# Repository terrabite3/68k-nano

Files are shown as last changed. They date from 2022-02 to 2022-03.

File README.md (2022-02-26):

# 68k nano

A minimal single-board computer based on the venerable ["Texas Cockroach"](https://youtu.be/UaHtGf4aRLs?t=2074)
Motorola 68000 16/32-bit microprocessor.

Board image

## Features

- 68HC000 processor running at 12MHz
- 1MB RAM
- 64KB ROM
- 16550 UART providing a 5V FTDI serial port
- 44-pin IDE connector for CompactFlash card adapter
- Connector for SparkFun DS3234 real-time clock
- Only two 74HC glue logic chips required

This might be capable of running uClinux, but I haven't tried it!

## Hardware

The 68k nano hardware is simple and straightforward. It can be built on a
breadboard (though there may be stability issues at higher clock speeds).

### Memory map

Due to the minimal address decoding circuitry, accessing certain memory regions
will cause multiple devices to be selected. This should be avoided.

```
$000000-0xFFFF     ROM (repeats 16 times)
$100000-1FFFFF  X  Forbidden (multiple devices selected)
$200000-2FFFFF     ROM (mirror of $000000-0FFFFF)
$300000-7FFFFF  X  Forbidden (multiple devices selected)
$800000-8FFFFF     Open bus (available for expansion)
$900000-9xxxxF     CompactFlash card
$A00000-AxxxxF     UART
$B00000-BFFFFF  X  Forbidden (multiple devices selected)
$C00000-CFFFFF     RAM
$D00000-DFFFFF  X  Forbidden (multiple devices selected)
$E00000-EFFFFF     RAM (mirror of $C00000-CFFFFF)
$F00000-FFFFFF  X  Forbidden (multiple devices selected)
```

This is summarized with the following equations:

```
/ROMSEL  = /A23
/RAMSEL  =  A22
/UARTSEL =  A23 * /A22 * A21
/CARDSEL =  A20
```

### I/O

The 16550's modem control lines are used as a bit-banged SPI interface. A 7-pin
header is provided for [SparkFun's "DeadOn" DS3234 real-time clock board](https://www.sparkfun.com/products/10160).
Access to SPI is therefore achieved via the 16550's Modem Control Register and Line
Status Register.

A 2mm pitch 44-pin IDE connector is provided for storage devices. This is
intended for CompactFlash card adapters (operating in 16-bit True IDE mode) but
may also work with parallel ATA hard disks. (not tested)

### Interrupts

All interrupt sources are routed through the 16550. All 16550 interrupts invoke
the level 1 autovector (vector offset `$064`) and it is up to the software to
determine the source of the interrupt.

### Building it

`bom.txt` contains a bill of materials. As of this writing (July 2020), all
components are available from major distributors like [Mouser](https://mouser.com)
and [Jameco](https://jameco.com). If purchasing 68000s from eBay, note that [vintage
ICs are a common target of counterfeiters](https://medium.com/supplyframe-hardware/the-underground-parts-store-identifying-counterfeit-computer-chips-3020adbb01f7).
For this project I used [Toshiba TMP68HC000P-12 chips from Jameco](https://www.jameco.com/shop/ProductDisplay?catalogId=10001&langId=-1&storeId=10001&productId=2288039) and
they work just fine.

All parts are through-hole for that extra vintage feel. Note that some of the
decoupling capacitors (C4, C5, C6, C8, and C10) are underneath ICs, so open-frame
IC sockets are required. Large IC sockets can also be expensive (_especially_
DIP-64 sockets!) so a cheaper alternative is to use [breakaway SIP 0.1" machine-pin
headers](https://www.amazon.com/dp/B0187LTEX2/ref=cm_sw_em_r_mt_dp_U_M5IbFbVJ3NVDH).

Due to the spacing of the chips, Textool ZIF sockets won't fit. For the ROMs
U5 and U7, [Aries 28-526-10 low-profile ZIF sockets](https://www.jameco.com/shop/ProductDisplay?catalogId=10001&langId=-1&storeId=10001&productId=102745) will fit,
but _barely_. The release latch may scrape against the RAM IC to its north,
but I've found that it's not a huge deal.

You can use either a full-can or half-can oscillator for X1. Note that if using
an oscillator with a frequency other than 12 MHz, you'll have to update the `F_CPU`
value in the Makefile. (see below) Also note that, if using a 68HC000, the minimum
clock frequency is 4 MHz.

The 44-pin IDE header accepts a CompactFlash adapter board such as [this one](https://www.amazon.com/gp/product/B07Y2MTS13), available from Amazon and other vendors.

## Software

This project uses the [vasm](http://sun.hasenbraten.de/vasm/) assembler and a
standard Makefile. Python 3 and [PySerial](https://pythonhosted.org/pyserial/)
are also required to upload programs to the computer via the serial port. The
Makefile also contains rules for burning ROM images to AT28C256 EEPROMs using
[minipro](https://gitlab.com/DavidGriffith/minipro/) if you have a [TL866II+](https://www.jameco.com/shop/ProductDisplay?catalogId=10001&langId=-1&storeId=10001&productId=2297823)
programmer. (If you don't have a chip programmer, you should get a TL866II+, they
are reasonably priced and available from a number of vendors.)

### Building it

Running `make rom` will build the ROM image and split it into "odd" and "even"
halves, `rom-l.bin` and `rom-u.bin`. Each file should be 32,768 bytes exactly.
Running `make burnrom` will write these files to a pair of AT28C256 EEPROMs
using minipro.

**Note:** if using an oscillator with a frequency other than 12 MHz, change the
value of `F_CPU` appropriately in the Makefile.

The `BAUD` variable in the Makefile sets the baud rate of the serial interface.
Use the included script `baudrate.py` to determine which baud rates are usable
with a given oscillator frequency.

### ROM features

The ROM is fairly minimal--it's closer to a bootloader than an operating system.
It supports loading programs from the root directory of a FAT16-formatted
CompactFlash card and some basic debugging functionality. It also provides a
small set of system calls for I/O to simplify application programs.

The power-up process is as follows:
- Initialize serial port to 57600 baud, 8 data bits, no parity, 1 stop bit.
- Test RAM. If a RAM failure occurs, the failed address is written to the serial
port and the Status LED flashes rapidly. (This is prone to failure when running
on a breadboard at higher clock speeds.)
- Check for the real-time clock module. If found, print the current date and
time to the serial port.
- Check for a CompactFlash card, and attempt to mount the first partition if it
is FAT16-formatted.
- If the "ENTER" pushbutton is NOT held down:
  - If a valid card is inserted, check for a file in the root directory named
    `STARTUP.BIN`. If found, load it into RAM and execute it.
  - If `STARTUP.BIN` was not loaded, enter an interactive command shell.
- If the "ENTER" pushbutton is held down, enter the interactive command shell
  and bypass execution of `STARTUP.BIN`.

Example startup sequence (without `STARTUP.BIN`):
```
68K NANO - ROM VERSION 00009900 (20200708)
(C) 2020 MATT SARNOFF (MSARNOFF.ORG)
TESTING RAM...PASSED

RAM: 1,048,576 BYTES
ROM: 65,536 BYTES
CPU: 12,000,000 HZ
TIME IS 2020-07-07 19:14:36
CARD DETECTED: 250,608 KB 'NO NAME    '
CANNOT LOAD STARTUP.BIN - FILE NOT FOUND

TYPE ? [ENTER] FOR HELP.
>
```

### Command shell

If `STARTUP.BIN` was not loaded, an interactive command shell is available via
the serial port. (57600 baud, 8 data bits, no parity, 1 stop bit). Type `?` and
press Enter for a list of supported commands. They are summarized briefly here.
Note that commands and filenames are _case-insensitive_.

- `.L` - list files in the root directory of the CompactFlash card. Long filenames
  and hidden files are not displayed.
- `.I` - print low-level information about the filesystem on the CompactFlash card.
- `.P file` - print the contents of the file named `file` in the root directory
  of the CompactFlash card as ASCII text.
- `.H file` - print the contenxt of the file named `file` in the root directory
  of the CompactFlash card as a hexdump.
- `.T` - print the current date and time as reported by the real-time clock module.
- `.T YYYYMMDDWWhhmmss` - set the current date and time. The new date/time should
  be expressed as a string of 16 decimal digits with no separators. `WW` should
  be a 2-digit weekday between `01` and `07` inclusive. You can obtain the
  current date/time in this format with the Unix command `date "+%Y%m%d0%u%H%M%S"`.
- `.D` - enter the debugger.
- `file` - any other command is interpreted as a filename to be loaded from the
  root directory of the CompactFlash card and executed. Unlike MS-DOS, the file
  extension _is_ required. e.g. to execute the file named _foo.bin_, enter `FOO.BIN`.
  (`FOO` will attempt to load a file named _foo_ with no extension).

### Serial loader

A break condition on the serial input line enters the serial loader, allowing
programs to be uploaded to RAM from a host computer. The Python script `serload.py`
and the Makefile rules `make load` and `make run` take care of this.

### Debugging

A hardware exception causes a transfer into a basic debugger. The Status LED
flashes rapidly and a register dump is printed to the serial port:

```
*ILLEGAL INSTRUCTION
D0=00000064  D1=0000000A  D2=00000038  D3=00000009
D4=00000000  D5=00000000  D6=00000000  D7=00000000
A0=00E0003C  A1=00001D40  A2=00000000  A3=00F00000
A4=00000000  A5=00000000  A6=000001E2  A7=00EFFFFA
SR=-S0--Z--  PC=00001D3A              USP=7F7EFFDF

[A]BORT/[C]ONTINUE/[S]TEP?
```

Supported commands are:
- `a` - abort execution and return to system.
- `c` - (attempt to) continue execution. (the Trace bit is cleared)
- `s` - set the Trace bit and single-step.

`TRAP #15` is treated as a breakpoint instruction that also enters the debugger.

### API

See `API.md` for a detailed description of the system calls provided by the ROM
API and guidelines for application programs.

## Known issues and shortcomings

- ROM is always present at the bottom of the address space, so the exception
  vectors cannot be overridden by application code.
- Interrupt handling is a hack, since all interrupt sources go through the 16550.
- Address decoding leaves little room for expansion.
- System calls should set the condition codes to simplify application code.

## Future directions

This is a small-scale project. I'm thinking about desiging a larger 68000 board
in the future, so I probably won't continue working on this one. Here are some
project ideas that I won't have time to tackle, but you're welcome to:

- Running an existing 68k monitor like [TUTOR](http://www.easy68k.com/paulrsm/mecb/mecb.htm)
  or [zBug](http://www.kswichit.com/68k/68k.html).
- Running a language like [EhBASIC](https://github.com/jefftranter/68000/tree/master/ehbasic) or a Forth.
- Adding FAT16 write support.
- Booting [uClinux](https://www.bigmessowires.com/2014/11/17/68-katy-68000-linux-on-a-solderless-breadboard/) like Steve Chamberlin did with [68 Katy](https://www.bigmessowires.com/category/68katy/).
- Using the DS3234 real-time clock's SQW output to generate a periodic interrupt.
  (likely necessary for uClinux)

## About

Open hardware, released under the terms of the 3-clause BSD license.

Copyright 2020 Matt Sarnoff.

http://twitter.com/txsector

http://msarnoff.org

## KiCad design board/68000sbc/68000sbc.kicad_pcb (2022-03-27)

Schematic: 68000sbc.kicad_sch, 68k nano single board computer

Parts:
C1, C2, C3, C4, C5, C6, C7, C8, C9, C10: 0.1uF; C_Rect_L7.0mm_W2.0mm_P5.00mm
C11, C12: 10uF; CP_Radial_D5.0mm_P2.50mm
D1, D2: 1N5817; D_DO-35_SOD27_P7.62mm_Horizontal
D3: POWER; LED_D5.0mm
D4: LED; LED_D5.0mm
D5: CARD; LED_D5.0mm
D6: HALT; LED_D5.0mm
J1: USB_B; USB_B_OST_USB-B1HSxx_Horizontal
J2: 5V FTDI SERIAL; PinHeader_1x06_P2.54mm_Horizontal
J3: RTC (SparkFun BOB-10160); PinHeader_1x07_P2.54mm_Vertical
J4: CFCARD/IDE; PinHeader_2x22_P2.00mm_Vertical
J5: EXPANSION (F.Cu); PadRow_1x25_P2.54mm
J6: EXPANSION (B.Cu); PadRow_1x25_P2.54mm
JP1: POWER SELECT; PinHeader_1x03_P2.54mm_Vertical
R1, R2: 10k; R_Axial_DIN0204_L3.6mm_D1.6mm_P7.62mm_Horizontal
R3: 1k; R_Axial_DIN0204_L3.6mm_D1.6mm_P7.62mm_Horizontal
R4, R5, R6, R7: 1k*; R_Axial_DIN0204_L3.6mm_D1.6mm_P7.62mm_Horizontal
RN1: 10k; R_Array_SIP7
SW1: RESET; SW_PUSH_6mm
SW2: BTN1; SW_PUSH_6mm
U1: 74HC139; DIP-16_W7.62mm_Socket
U2: 74HC14; DIP-14_W7.62mm_Socket
U3: TMP68HC000P-12; DIP-64_W22.86mm_Socket
U4, U6: AS6C4008-55PCN; DIP-32_W15.24mm_Socket
U5, U7: 28C256; DIP-28_W15.24mm_Socket
U8: TL16C550; DIP-40_W15.24mm_Socket
X1: 12MHz; Oscillator_DIP-14
X2: 12MHz; Oscillator_DIP-8

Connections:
/A1: J4.35, J6.21, U3.29 (A1), U4.12 (A0), U5.10 (A0), U6.12 (A0), U7.10 (A0), U8.28 (A0)
/A2: J4.33, J5.21, U3.30 (A2), U4.11 (A1), U5.9 (A1), U6.11 (A1), U7.9 (A1), U8.27 (A1)
/A3: J4.36, J6.23, U3.31 (A3), U4.10 (A2), U5.8 (A2), U6.10 (A2), U7.8 (A2), U8.26 (A2)
/A4: J6.16, U3.32 (A4), U4.9 (A3), U5.7 (A3), U6.9 (A3), U7.7 (A3)
/A5: J6.14, U3.33 (A5), U4.8 (A4), U5.6 (A4), U6.8 (A4), U7.6 (A4)
/A6: J5.11, U3.34 (A6), U4.7 (A5), U5.5 (A5), U6.7 (A5), U7.5 (A5)
/A7: J6.11, U3.35 (A7), U4.6 (A6), U5.4 (A6), U6.6 (A6), U7.4 (A6)
/A8: J5.12, U3.36 (A8), U4.5 (A7), U5.3 (A7), U6.5 (A7), U7.3 (A7)
/A9: J5.19, U3.37 (A9), U4.27 (A8), U5.25 (A8), U6.27 (A8), U7.25 (A8)
/A10: J6.12, U3.38 (A10), U4.26 (A9), U5.24 (A9), U6.26 (A9), U7.24 (A9)
/A11: J5.17, U3.39 (A11), U4.23 (A10), U5.21 (A10), U6.23 (A10), U7.21 (A10)
/A12: J6.20, U3.40 (A12), U4.25 (A11), U5.23 (A11), U6.25 (A11), U7.23 (A11)
/A13: J5.18, U3.41 (A13), U4.4 (A12), U5.2 (A12), U6.4 (A12), U7.2 (A12)
/A14: J6.18, U3.42 (A14), U4.28 (A13), U5.26 (A13), U6.28 (A13), U7.26 (A13)
/A15: J6.19, U3.43 (A15), U4.3 (A14), U5.1 (A14), U6.3 (A14), U7.1 (A14)
/A16: J5.9, U3.44 (A16), U4.31 (A15), U6.31 (A15)
/A17: J6.9, U3.45 (A17), U4.2 (A16), U6.2 (A16)
/A18: J5.10, U3.46 (A18), U4.30 (A17), U6.30 (A17)
/A19: J6.8, U3.47 (A19), U4.1 (A18), U6.1 (A18)
/A20: J6.6, U2.11, U3.48 (A20)
/A21: J6.10, U3.50 (A21), U8.12 (CS0)
/A22: J5.6, U2.9, U3.51 (A22), U8.14 (~CS2)
/A23: J5.8, U3.52 (A23), U5.20 (~CS), U7.20 (~CS), U8.13 (CS1)
/CFIRQ: J4.31
/CPUCLK: J5.1, U3.15 (CLK), U8.16 (XIN), X1.8 (OUT), X2.5 (OUT)
/D0: J4.17, J5.2, U3.5 (D0), U4.13 (DQ0), U5.11 (D0)
/D1: J4.15, J6.2, U3.4 (D1), U4.14 (DQ1), U5.12 (D1)
/D2: J4.13, J5.3, U3.3 (D2), U4.15 (DQ2), U5.13 (D2)
/D3: J4.11, J6.3, U3.2 (D3), U4.17 (DQ3), U5.15 (D3)
/D4: J4.9, J5.4, U3.1 (D4), U4.18 (DQ4), U5.16 (D4)
/D5: J4.7, J6.4, U3.64 (D5), U4.19 (DQ5), U5.17 (D5)
/D6: J4.5, J5.5, U3.63 (D6), U4.20 (DQ6), U5.18 (D6)
/D7: J4.3, J6.5, U3.62 (D7), U4.21 (DQ7), U5.19 (D7)
/D8: J4.4, J5.7, U3.61 (D8), U6.13 (DQ0), U7.11 (D0), U8.1 (D0)
/D9: J4.6, J6.7, U3.60 (D9), U6.14 (DQ1), U7.12 (D1), U8.2 (D1)
/D10: J4.8, J5.20, U3.59 (D10), U6.15 (DQ2), U7.13 (D2), U8.3 (D2)
/D11: J4.10, J5.23, U3.58 (D11), U6.17 (DQ3), U7.15 (D3), U8.4 (D3)
/D12: J4.12, J6.15, U3.57 (D12), U6.18 (DQ4), U7.16 (D4), U8.5 (D4)
/D13: J4.14, J5.15, U3.56 (D13), U6.19 (DQ5), U7.17 (D5), U8.6 (D5)
/D14: J4.16, J5.14, U3.55 (D14), U6.20 (DQ6), U7.18 (D6), U8.7 (D6)
/D15: J4.18, J5.13, U3.54 (D15), U6.21 (DQ7), U7.19 (D7), U8.8 (D7)
/EXTIRQ: J6.24, RN1.5 (R4), U8.36 (~CTS)
/IRQ: U2.13, U8.30 (INTR)
/R,~W: U1.2 (A0), U1.14 (A0), U3.9 (R/W)
/RESET: J5.24, U2.2, U8.35 (MR)
/RTC_CIPO: J3.5, RN1.3 (R2), U8.38 (~DCD)
/RTC_CLK: J3.4, U8.34 (~OUT1)
/RTC_COPI: J3.6, U8.33 (~DTR)
/RTC_SQW: J3.3, RN1.4 (R3), U8.37 (~DSR)
/RXD: J2.5, U8.11 (SOUT)
/TXD: J2.4, RN1.6 (R5), U8.10 (SIN)
/~A20: J4.37, U2.10
/~A22: U2.8, U4.22 (CE#), U6.22 (CE#)
/~AS: U1.3 (A1), U1.13 (A1), U3.6 (AS)
/~BTN1: RN1.2 (R1), SW2.2, U8.39 (~RI)
/~CFLED: J4.39, R4.1
/~HALT: D2.2 (A), D6.1 (K), R1.2, U3.17 (HALT)
/~IRQ: U2.12, U3.21 (VPA), U3.25 (IPL0)
/~LDS: U1.1 (E), U3.8 (LDS)
/~RDL: J4.25, J5.16, U1.5 (O1), U4.24 (OE#), U5.22 (~OE)
/~RDU: J6.22, U1.11 (O1), U6.24 (OE#), U7.22 (~OE), U8.21 (~RD)
/~RESETBTN: R3.2, RN1.7 (R6), SW1.2
/~RESET: D1.2 (A), J4.1, J6.1, R2.2, U2.1, U3.18 (RESET)
/~RTC_SS: J3.7, U8.31 (~OUT2)
/~UDS: U1.15 (E), U3.7 (UDS)
/~WRL: J4.23, J6.17, U1.4 (O0), U4.29 (WE#)
/~WRU: J5.22, U1.12 (O0), U6.29 (WE#), U8.18 (~WR)
GND: C1.2, C2.2, C3.2, C4.2, C5.2, C6.2, C7.2, C8.2, C9.2, C10.2, C11.2, C12.2, D3.1 (K), J1.4 (GND), J1.5 (Shield), J2.1, J3.1, J4.2, J4.19, J4.22, J4.24, J4.26, J4.30, J4.40, J4.43, J5.25, J6.25, SW1.1, SW2.1, U1.8 (GND), U2.7 (GND), U3.10 (DTACK), U3.16 (GND), U3.53 (GND), U4.16 (VSS), U5.14 (GND), U6.16 (VSS), U7.14 (GND), U8.19 (WR), U8.20 (GND), U8.22 (RD), U8.25 (~ADS), X1.7 (GND), X2.4 (GND)
unnamed: C11.1, R3.1, U2.5
unnamed: D1.1 (K), D2.1 (K), U2.4
unnamed: D3.2 (A), R6.1
unnamed: D4.1 (K), U8.32 (~RTS)
unnamed: D4.2 (A), R5.2
unnamed: D5.1 (K), R4.2
unnamed: D6.2 (A), R7.1
unnamed: J1.1 (VBUS), JP1.3 (B)
unnamed: J2.3, JP1.1 (A)
unnamed: U2.3, U2.6
unnamed: U8.9 (RCLK), U8.15 (~BAUDOUT)
unnamed: X1.1 (EN), X2.1 (EN)
VCC: C1.1, C2.1, C3.1, C4.1, C5.1, C6.1, C7.1, C8.1, C9.1, C10.1, C12.1, D5.2 (A), J3.2, J4.38, J4.41, J4.42, J6.13, JP1.2 (C), R1.1, R2.1, R5.1, R6.2, R7.2, RN1.1 (common), U1.16 (VCC), U2.14 (VCC), U3.12 (BGACK), U3.13 (BR), U3.14 (VCC), U3.22 (BERR), U3.23 (IPL2), U3.24 (IPL1), U3.49 (VCC), U4.32 (VCC), U5.27 (~WE), U5.28 (VCC), U6.32 (VCC), U7.27 (~WE), U7.28 (VCC), U8.40 (VCC), X1.14 (Vcc), X2.8 (Vcc)

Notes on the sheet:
Full can
GND
MSR[6]
ORG
MCR[1]
Populate only one!
A23-A20 0000 0001 0010 0011 0100 0101 0110 0111 1000 1001 1010 1011 1100 1101 1110 1111
* R4, R5, R6, R7: Choose resistor value based on LED forward voltage and desired indicator brightness.
CLK
MCR[2]
(UPPER)
Half can
SQW
MCR[3]
YEL
~{IRQ} invokes autovector 1
(LOWER)
COPI
VCC
GRN
Maps to ROM ROM + CFCARD (forbidden) ROM ROM + CFCARD (forbidden) ROM + RAM (forbidden) ROM + RAM + CFCARD (forbidden) ROM + RAM (forbidden) ROM + RAM + CFCARD (forbidden) None (open bus) CFCARD UART UART + CFCARD (forbidden) RAM RAM + CFCARD (forbidden) RAM RAM + CFCARD (forbidden)
ROM selected when A23=0 RAM selected when A22=1 UART selected when A23=1 and A22=0 and A21=1 CFCARD selected when A20=1
MSR[7]
BRN
MCR[0]
~{SS}
KEY
Modem control lines can be used for bit-banged SPI.
MSR[5]
CIPO
MSR[4]
RED

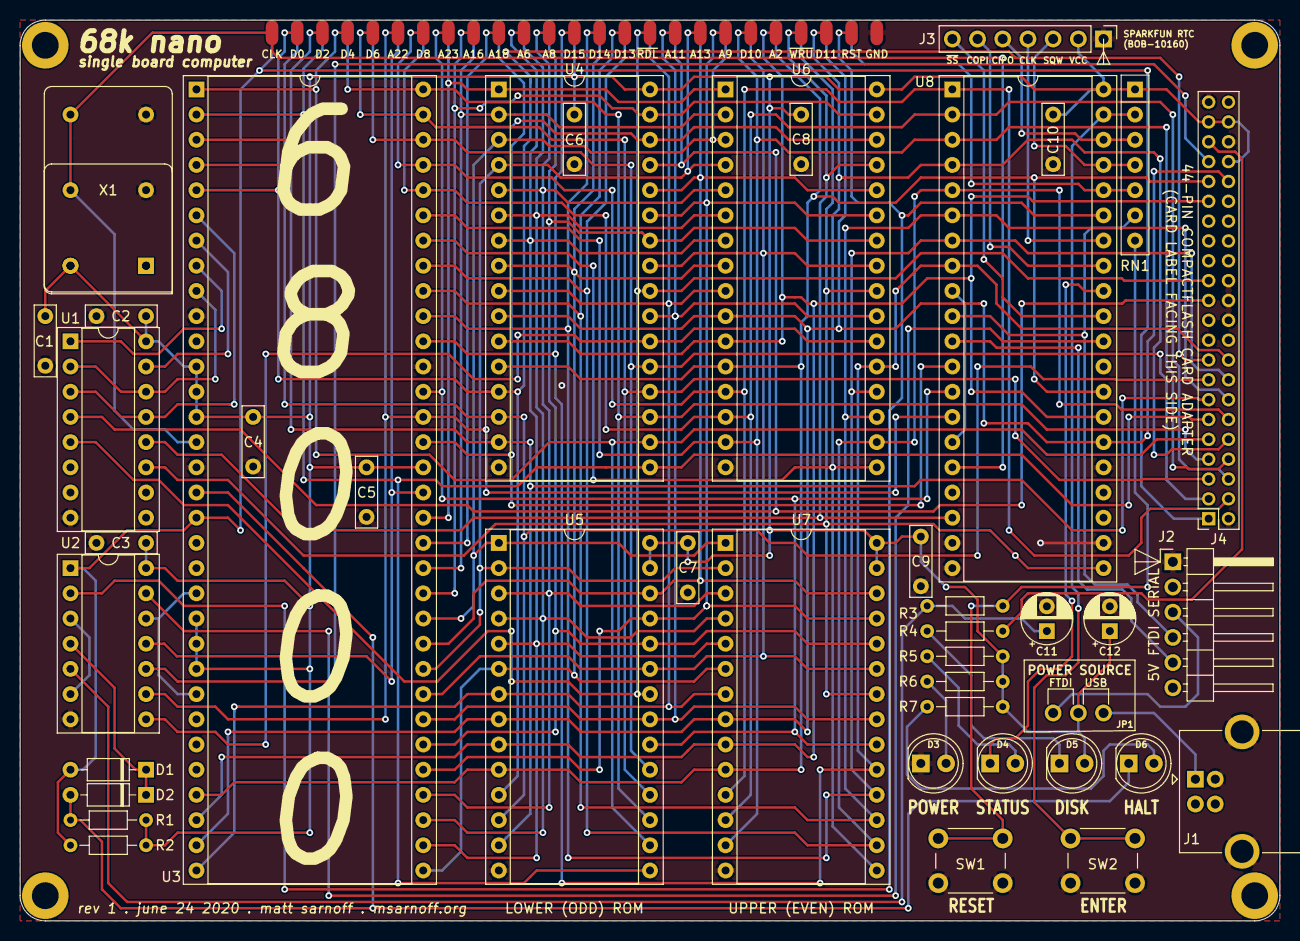
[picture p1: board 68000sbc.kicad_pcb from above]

Board: 2 copper layers, 127.0 x 90.8 mm, 45 parts (1 on the bottom side), 80 nets.

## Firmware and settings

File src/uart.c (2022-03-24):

#include "uart.h"

#include "type.h"


// The UART is connected to the upper half of the data bus, 
// which means it is accessed at even addresses
volatile char * const uart     = (char *) 0xA00000;
volatile char * const uart_RBR = (char *) 0xA00000; // Receiver Buffer Register (Read)
volatile char * const uart_THR = (char *) 0xA00000; // Transmitter Holding Register (Write)
volatile char * const uart_DLL = (char *) 0xA00000; // Divisor LSB (set DLAB first)
volatile char * const uart_IER = (char *) 0xA00002; // Interrupt Enable Register
volatile char * const uart_DLM = (char *) 0xA00002; // Divisor MSB (set DLAB first)
volatile char * const uart_IIR = (char *) 0xA00004; // Interrupt Ident. Register (Read)
volatile char * const uart_FCR = (char *) 0xA00004; // FIFO Control Register (Write)
volatile char * const uart_LCR = (char *) 0xA00006; // Line Control Register
volatile char * const uart_MCR = (char *) 0xA00008; // Modem Control Register
volatile char * const uart_LSR = (char *) 0xA0000A; // Line Status Register
volatile char * const uart_MSR = (char *) 0xA0000C; // Modem Status Register
volatile char * const uart_SCR = (char *) 0xA0000E; // Scratch Register


void setup38400()
{
    // 8 data bits, 1 stop bit, no parity, DLAB
    *uart_LCR = 0b10000011;
    // the ROM writes 0x09 to DLL, 0x00 to DLM
    // We'll set DLL to 13, DLM to 0 for a much better approximation of 38400
    // than we can get to 57600 with an 8MHz crystal
    *uart_DLL = 13;
    *uart_DLM = 0;
    *uart_LCR = 0b00000011;
}

void printString(const char* s)
{
    while (*s)
    {
        // Check THRE - transmitter holding register empty
        if (*uart_LSR & 0x20)
        {
            *uart = *s;
            s++;
        }
    }
}

void printHex16(uint16_t num)
{
    char digits[7];
    digits[0] = '0';
    digits[1] = 'x';
    digits[6] = 0;
    for (uint8_t i = 0; i < 4; ++i)
    {
        uint8_t x = (num >> (12 - 4 * i)) & 0xF;
        if (x < 10) 
            digits[i + 2] = x + '0';
        else
            digits[i + 2] = x + 'A' - 10;
    }
    printString(digits);
}

void printHex16No0x(uint16_t num)
{
    char digits[5];
    digits[4] = 0;
    for (uint8_t i = 0; i < 4; ++i)
    {
        uint8_t x = (num >> (12 - 4 * i)) & 0xF;
        if (x < 10) 
            digits[i] = x + '0';
        else
            digits[i] = x + 'a' - 10;
    }
    printString(digits);
}

char printableOrDot(char c)
{
    if (c >= ' ' && c <= '~')
        return c;
    else
        return '.';
}

void printHexBuffer(uint16_t* buffer, uint16_t buffer_len)
{
    uint16_t completeRows = buffer_len / 8;
    uint16_t wordsOnIncompleteRow = buffer_len % 8;

    for (uint16_t row = 0; row < completeRows; ++row)
    {
        uint16_t offset = row << 3;
        printHex16No0x(row << 4);
        printString(": ");

        char text[17];
        text[16] = 0;

        for (uint8_t col = 0; col < 8; ++col)
        {
            printHex16No0x(buffer[col + offset]);
            printString(" ");

            text[2 * col + 1] = printableOrDot(buffer[col + offset] & 0xFF);
            text[2 * col] = printableOrDot((buffer[col + offset] >> 8) & 0xFF);
        }

        printString(" ");
        printString(text);
        printString("\n");
    }
}

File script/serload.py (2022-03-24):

#!/usr/bin/env python3

# Very basic serial loader.
# Does no checking/verification that the upload succeeded
# Code is always loaded into the same location in RAM. (APPMEMSTART)
#
# protocol is:
# - host (this script) sends break condition
# - target (the board) replies with ASCII U
# - host sends entire binary image
# - host sends break condition
# - target reboots

import serial
import sys
import time
import glob

BAUD = 57600

if len(sys.argv) != 2:
    print('usage: serload.py <binfile>')
    sys.exit(1)

serial_devs = glob.glob('/dev/cu.usbserial-*')
if len(serial_devs) == 0:
    print("Couldn't find a serial port")
    sys.exit(1)

serial_dev = serial_devs[0]

with open(sys.argv[1], 'rb') as infile:
    ser = serial.Serial(serial_dev, BAUD, timeout=1)
    # enter loader
    ser.send_break()
    # wait for acknowledge
    ack = ser.read(20)
    print(ack)
    if ack != b'U':
      raise IOError('device did not acknowledge')
    # write bytes
    ser.write(infile.read())
    ser.flush()
    # additional delay sometimes required when sending short files
    # on macOS (dee to closing the serial port too soon?
    time.sleep(0.1)
    # send a break to finish
    ser.send_break()

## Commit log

2022-02-26 Add Docker-based gcc toolchain
    C++ isn't working yet. GCC fails to build when I enable it in configure.
    [serload.py]
2022-03-24 Add basic UART print support
    Using 38400 baud because 57600 baud can't be properly approximated with an 8 MHz crystal.
2022-03-27 Move CompactFlash and FAT code out of the submodule
    There's not much reason to track this as a submodule when I'm modifying it so much for this project.
    There's a lot of debug code in there right now.
2022-03-27 Move KiCad stuff to a subdirectory
    [68000sbc.kicad_pcb, 68000sbc.kicad_sch, 68000sbc.sch]
2022-03-27 Remove unused code from CompactFlash FAT driver
2022-03-27 Move internal members to .c file as is conventional
    The original driver defines all internal global variables and functions in the .h files alongside the external ones. They use a define to choose whether the header should declare variables as extern 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
